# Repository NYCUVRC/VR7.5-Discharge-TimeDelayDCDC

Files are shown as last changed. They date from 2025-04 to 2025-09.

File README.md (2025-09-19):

# VR7.5-Discharge-TimeDelayDCDC
A KiCad project for Discharge&amp;TimeDelayDCDC PCB

## Front
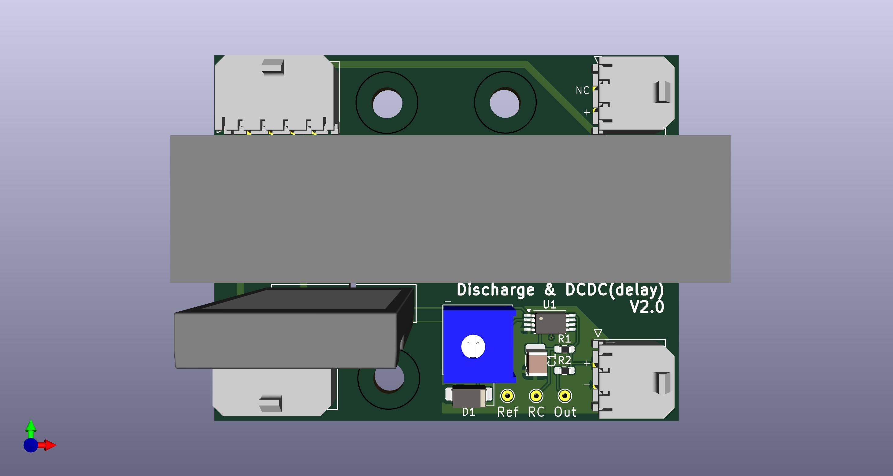
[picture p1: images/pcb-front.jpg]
front


## Back
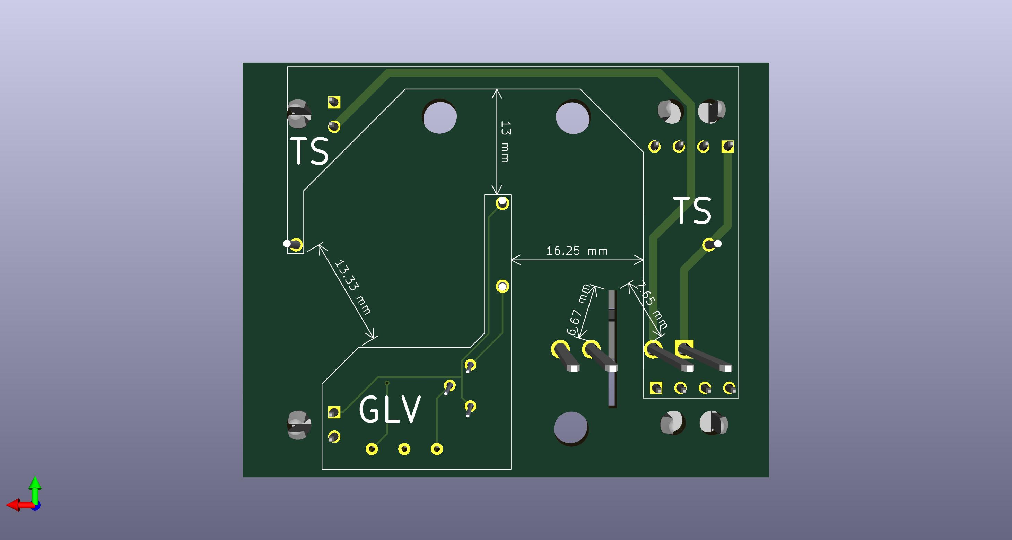
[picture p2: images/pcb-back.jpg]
back


## Features
- [x] Schematic
  - [x] At least 5s Time Delay on DCDC output
  - [x] Flyback Diode beside coils
  - [x] ALL Spice Model
  - [x] Simulation Success
  - [x] Electrical Rules Check(ERC)
- [x] PCB
  - [x] Mounting Holes
  - [x] Test Points
  - [x] Wide Traces on HV
  - [x] Mark Distance between HV and LV
  - [x] Ground Plane
  - [x] Version Number
  - [x] Design Rules Check(DRC)
- [ ] Manufacturing
  - [x] Gerber Files
  - [x] Drill Files
  - [x] BOM
  - [ ] Pick and Place File
- [x] Assembly
  - [x] Soldering
  - [x] Testing
  - [x] Debugging

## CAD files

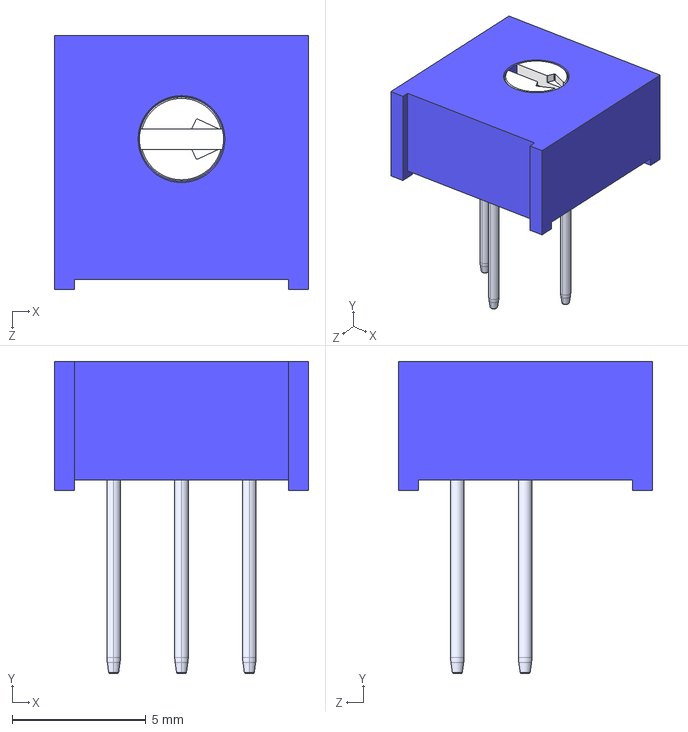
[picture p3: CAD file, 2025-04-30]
3386P-DF6-104/3386P-DF6-104.STEP
9.53 x 11.7 x 9.53 mm

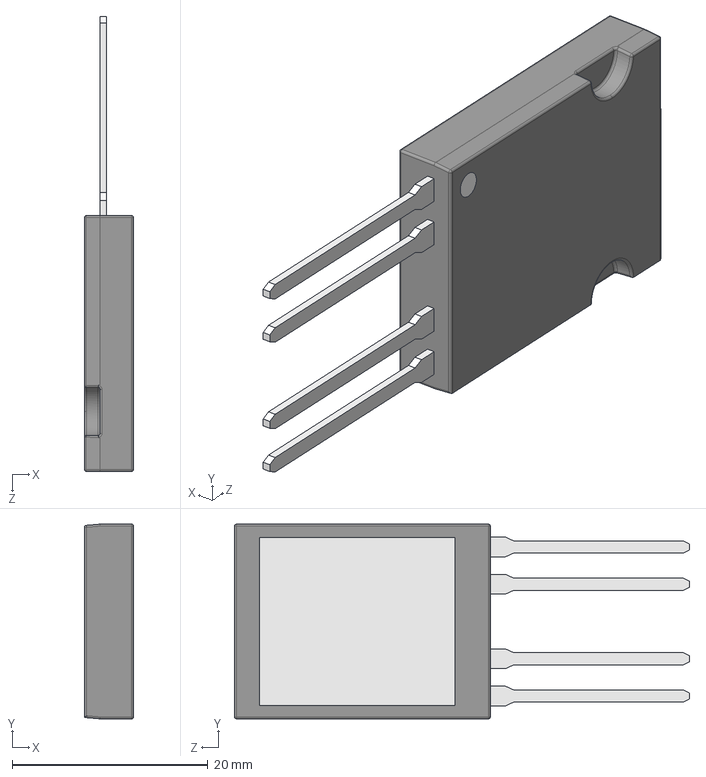
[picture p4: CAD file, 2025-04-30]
CPC1968J/CPC1968J.stp
5.03 x 19.9 x 46.5 mm

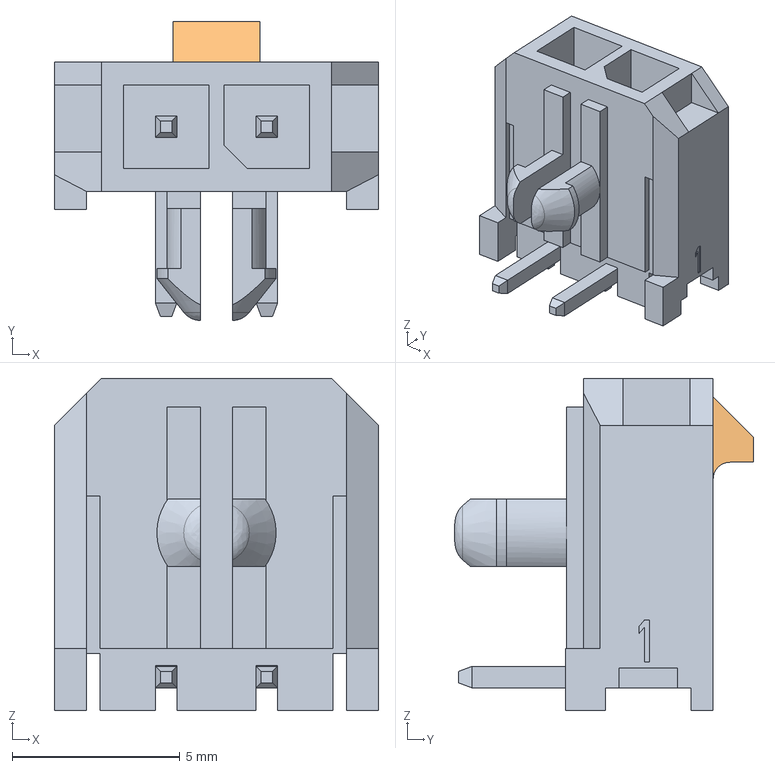
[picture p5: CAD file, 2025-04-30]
43650-0200/43650-0200.stp
9.65 x 8.91 x 9.90 mm

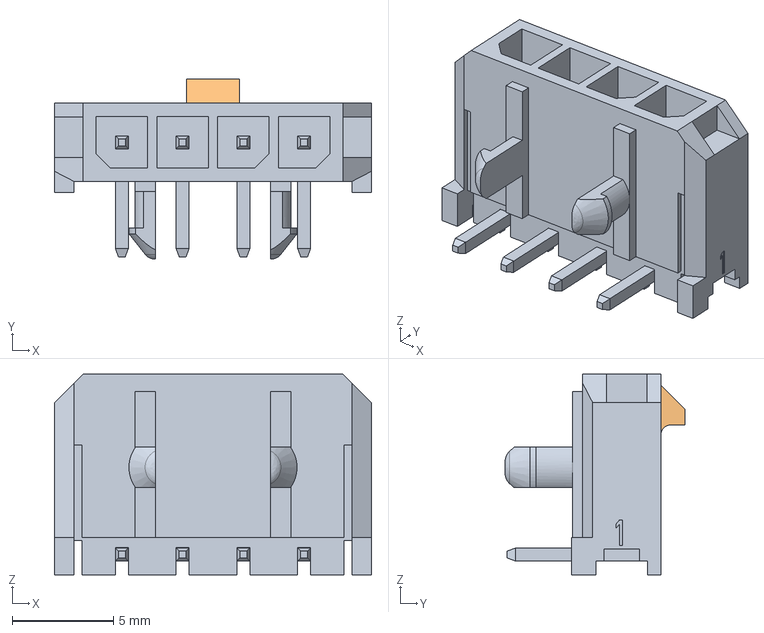
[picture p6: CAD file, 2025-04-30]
43650-0400/43650-0400.stp
15.7 x 8.91 x 9.90 mm

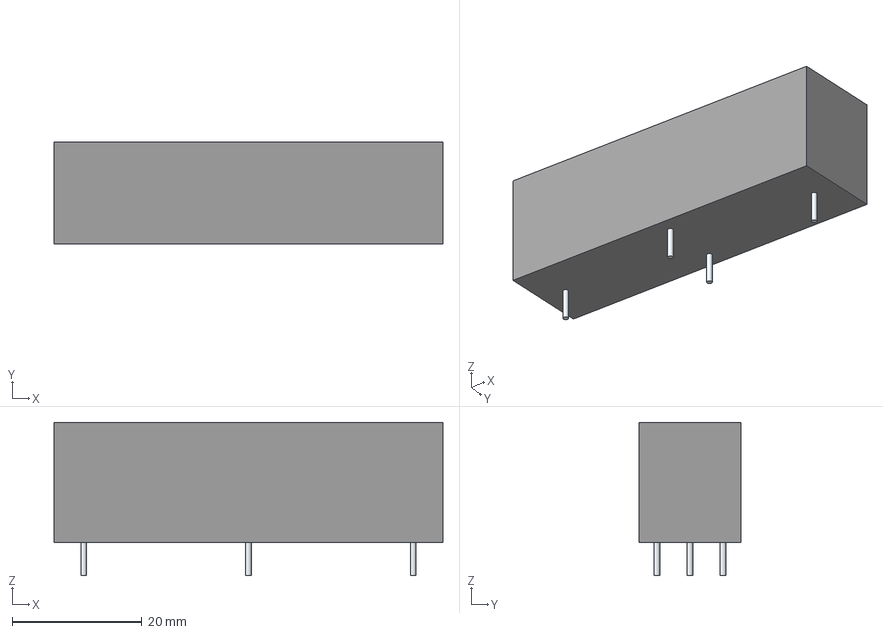
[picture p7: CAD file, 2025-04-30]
DBT71205U/DBT71205U.stp
60.0 x 15.8 x 23.6 mm
Leads

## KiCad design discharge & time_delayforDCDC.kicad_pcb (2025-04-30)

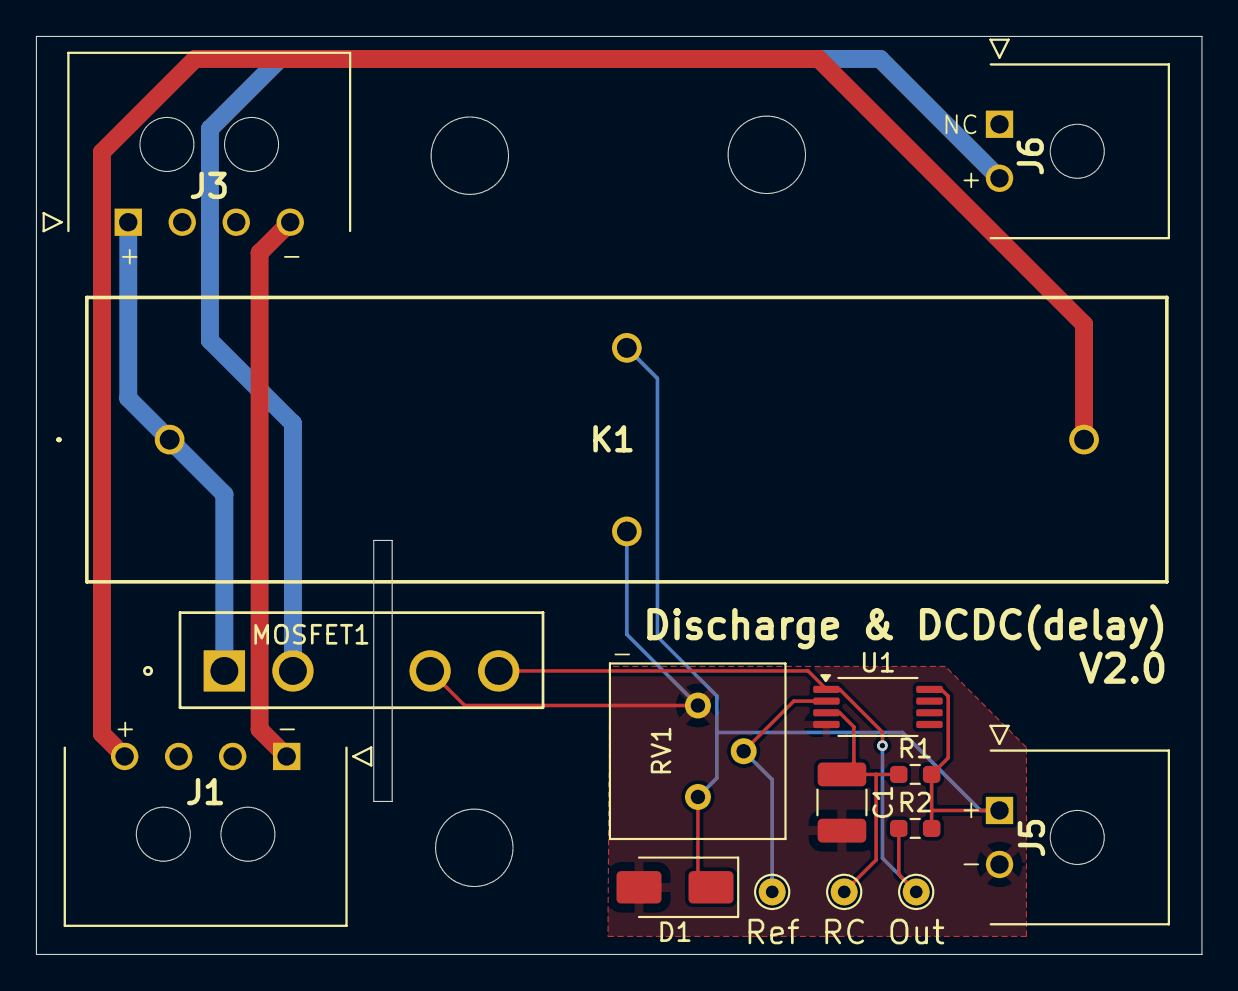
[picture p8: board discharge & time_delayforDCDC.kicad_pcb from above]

Board: 2 copper layers, 64.8 x 51.0 mm, 18 parts (0 on the bottom side), 9 nets.

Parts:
C1: 100u; C_1210_3225Metric_Pad1.33x2.70mm_HandSolder
D1: US1J; D_SMA
H1, H2, H3: MountingHole; MountingHole_4.3mm_M4
J1, J3: 43650-0400; 43650-04_00,01,02_
J5, J6: 43650-0200; 43650-02_00,01,02_
K1: DBT71205U
MOSFET1: CPC1968J; ISOPLUS-264_19P914X5P029_IXY
R1: 50k; R_0603_1608Metric_Pad0.98x0.95mm_HandSolder
R2: 1k; R_0603_1608Metric_Pad0.98x0.95mm_HandSolder
RV1: R_Potentiometer; Potentiometer_Bourns_3386P_Vertical
TP1, TP2, TP3: TestPoint; TestPoint_THTPad_D1.5mm_Drill0.7mm
U1: LM393; TSSOP-8_4.4x3mm_P0.65mm

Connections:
/Delay: C1.1, R1.1, TP1.1, U1.3 (+)
/Enable: MOSFET1.4, R2.1, TP2.1, U1.1
/Ref: RV1.2, TP3.1, U1.2 (-)
DCDC: J6.2, MOSFET1.2
Discharge: J1.4, K1.2 (out-)
GND: C1.2, D1.2 (A), J5.2, K1.3 (-), MOSFET1.3, RV1.3, U1.4 (V-)
SDC: D1.1 (K), J5.1, K1.4 (+), R1.2, R2.2, RV1.1, U1.8 (V+)
TS+: J3.1, K1.1 (out+), MOSFET1.1
TS-: J1.1, J3.4

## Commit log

2025-04-30 upload pcb images
2025-04-30 feat: add manufacturing and assembly sections to README
2025-04-30 Update schematic and PCB
    - Modified properties of test points to exclude from simulation and removed from BOM
    - Fix wrong rating of the capacitor
    - Updated footprint
    - Updated image file
    [discharge & time_delayforDCDC-B_Cu.gbr, discharge & time_delayforDCDC-B_Mask.gbr, discharge & time_delayforDCDC-B_Paste.gbr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]
2025-04-30 Update README.md
    - add back pcb image
2025-04-30 remove Gerber - Only download Gerbers on Release page
    [discharge & time_delayforDCDC-B_Cu.gbr, discharge & time_delayforDCDC-B_Mask.gbr, discharge & time_delayforDCDC-B_Paste.gbr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]
